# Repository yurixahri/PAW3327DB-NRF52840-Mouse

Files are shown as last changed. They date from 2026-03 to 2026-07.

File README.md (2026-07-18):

This is a mouse project for PAW3327DB‐TWQU sensor and Supermini nrf52840 board.

# Necessary components:
| component | quanlity | note |
| :--- | :---: | -----|
| Supermini nrf52840 | 2 | |
| PAW3327DB‐TWQU | 1 | please buy with its len and led |
| TTP223 touch sensor | 2 | buy the chip, not the board |
| 0805 100nf capacitor | 4 | |
| 0805 10uf capacitor | 2 | |
| 0805 33pf capacitor | 2 | |
| 0805 10kΩ resistor | 2 | |
| 0805 33Ω resistor | 1 | |
| Molex picoblade female 1.25mm 4 pins horizontal | 2 | for scroll and middle button |
| Molex picoblade female 1.25mm 3 pins horizontal | 2 | for left side buttons |
| Molex picoblade female 1.25mm 2 pins vertucal | 1 | for battery |
| Molex picoblade male cable 1.25mm 4,3,2 pins | several | just buy more than you need, in case of you want to adjust the cable length |
| 3x2x9 500mah battery | 1 | |
| Low profile keyboard switch | 2 | any brand will work |
| Mouse switch (2 pins) | 3 | So i used mouse switch and noticed that the its height is quite high and block the touch point on scroll pcb, so i instead use 3x6x2.5mm smd button (2 pins) |
| 6x6mm tactile switch | 2 | for DPI and reset button |
| 3 pins spdt slide switch | 1 | to turn on/off battery |

# Mouse schematic:
mouse

This PAW3327DB‐TWQU schematic is followed in the sensor data sheet (P.18 [here](https://gzhls.at/blob/ldb/e/9/c/9/db61cdd17b4364badf6f0cfc864d7ef28cb3.pdf)).
Two 33pf capacitors (C6 and C7) are sensitivity capacitor for TTP223, the range from 0 to 50pf, the larger value the less sensitivity of the TTP223.

A note for the battery that if you use 500mah or larger battery, please connect the BOOST pad on the Supermini nrf52840.



# PCB:
This design has 3 parts but i had to combine them in to one board to cut cost. You can safely cut it with handsaw, and use sand paper to smooth the edge.



# Mouse case
| component | quanlity | note |
| :--- | :---: | -----|
| M2 Hex Female-Female Standoff 4mm | 4 | for main pcb |
| M2 Hex Female-Female Standoff 10mm | 2 | for scroll pcb standoff |
| M2 bolt 6mm | several | |
| M2 nut | several | |

I followed PAW3327DB‐TWQU [datasheet](https://gzhls.at/blob/ldb/e/9/c/9/db61cdd17b4364badf6f0cfc864d7ef28cb3.pdf) (P.11-15).
In this repo i design one with autocad (i dont have knowledge about 3d print), it just a prototype but i used it for sevaral months now, seems fine.

# Firmware
There are 2 codes, one for the mouse and one for receiver. To build it please install Visual Code and install nRF Connect extension for the sake of simplicity, it will install SDK and compiler for you.
Then open those 2 folders in VS Code.



To build it, navigate to nRF connect tab and create build configuration.



For Supermini nrf52840, follow this setting.



After you completed the building, it will create the firmware at ../build/zephyr/zephyr.hex . Then use the python script (with the json file in the same folder) in this repo to convert the hex to uf2 with the command:
`python uf2conv.py "path/to/your/zephyr.hex" -c -f 0xADA52840`
Finally to flash the firmware to the board, connect your board to your computer, quickly connect reset pin to GND 2 times, when you see the led slowly fading it means the board is in bootloader mode. On your computer now will show the drive of the board, simply copy the uf2 firmware to the drive and it will flash the board.

# Notes
- In nRF build configuration, at the board target it does have uf2 option for this board, but for some reason it cant be flash to the board so i have to convert the hex myself
- In both of the code for the mouse and the receiver, there is esb address for rf signal, you should change it to your desire address (base_addr_0), and the address should be the same for both sides.


- In mouse code, i commented out some of the interupt code, last time i was testing the motion pin and interupt but it feel delay, so i kept the code with polling style. because of it the battery usage is around 1.5 days of intense use with some break (im not familiar with embedded stuff, so my code is kinda ugly).
- When mouse idle for more than 4 mins, it will shutdown until you press left click.
- DPI value in mouse code is hand measurement, i use a ruler to calculate the resolution value of the mouse sensor, around 102 is equilevent to 3200 DPI.
- Also in mouse code, i commented out the setting function, nRF have local storage for setting, but last time i used it somehow brick the board. So for safety concern i don't use that function.
- I was experimenting with some code, and made the board brick. I recommend you to update the board bootloader to newest nicenano bootloader ([here](https://github.com/adafruit/Adafruit_nRF52_Bootloader/releases)), use j-link (or if you don't have j-link usb, use a spare board like pico or rp2040 based board with Picoprobe firmware), connect correct pins to nrf52480 swd pads (swdclk, swdio and ground, use usb to power it) and upload via pyocd (open Nrf Connect terminal in visual code and run)
  ```
  pyocd erase -t nrf52840 --chip
  pyocd flash -t nrf52840 nice_nano_bootloader-0.11.0_s140_6.1.1.hex
  ```

# Demo (early prototype)
https://github.com/user-attachments/assets/07815808-ed37-4bc4-9238-eaf0a6d82ae9

New version (I cheaped out all Molex picoblade for this prototype):



# Thought
The cost per mouse is arround 12-15$, which is quite cheap to be fair, especially when you buy the components in bulk (1$ for 20 TTP223 sensors!). Goodluck if you want to make mouse!

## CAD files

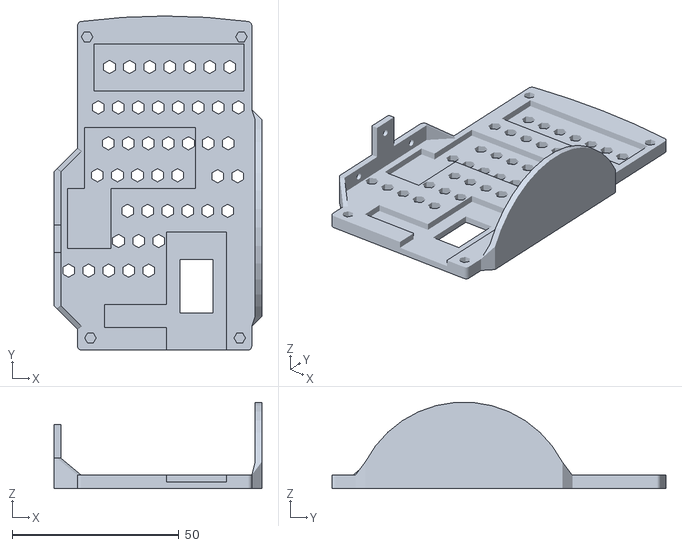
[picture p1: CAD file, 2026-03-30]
mouse3d_holes.stl
62.2 x 100.1 x 25.8

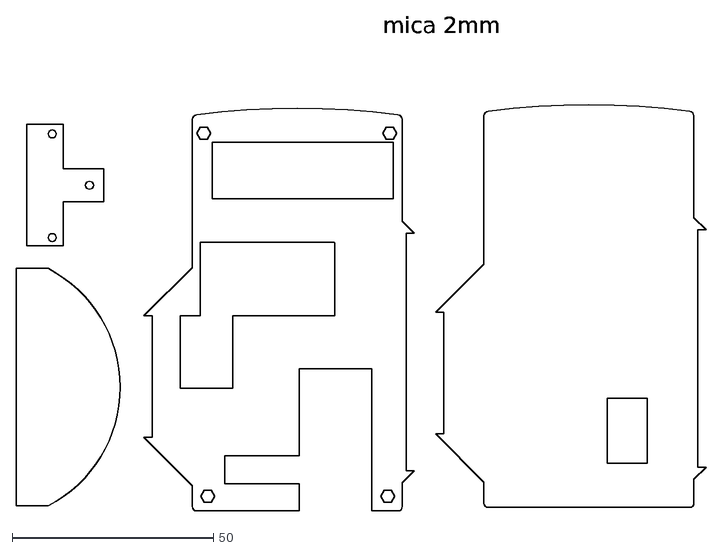
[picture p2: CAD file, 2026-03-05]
mouse.dxf
mica 2mm

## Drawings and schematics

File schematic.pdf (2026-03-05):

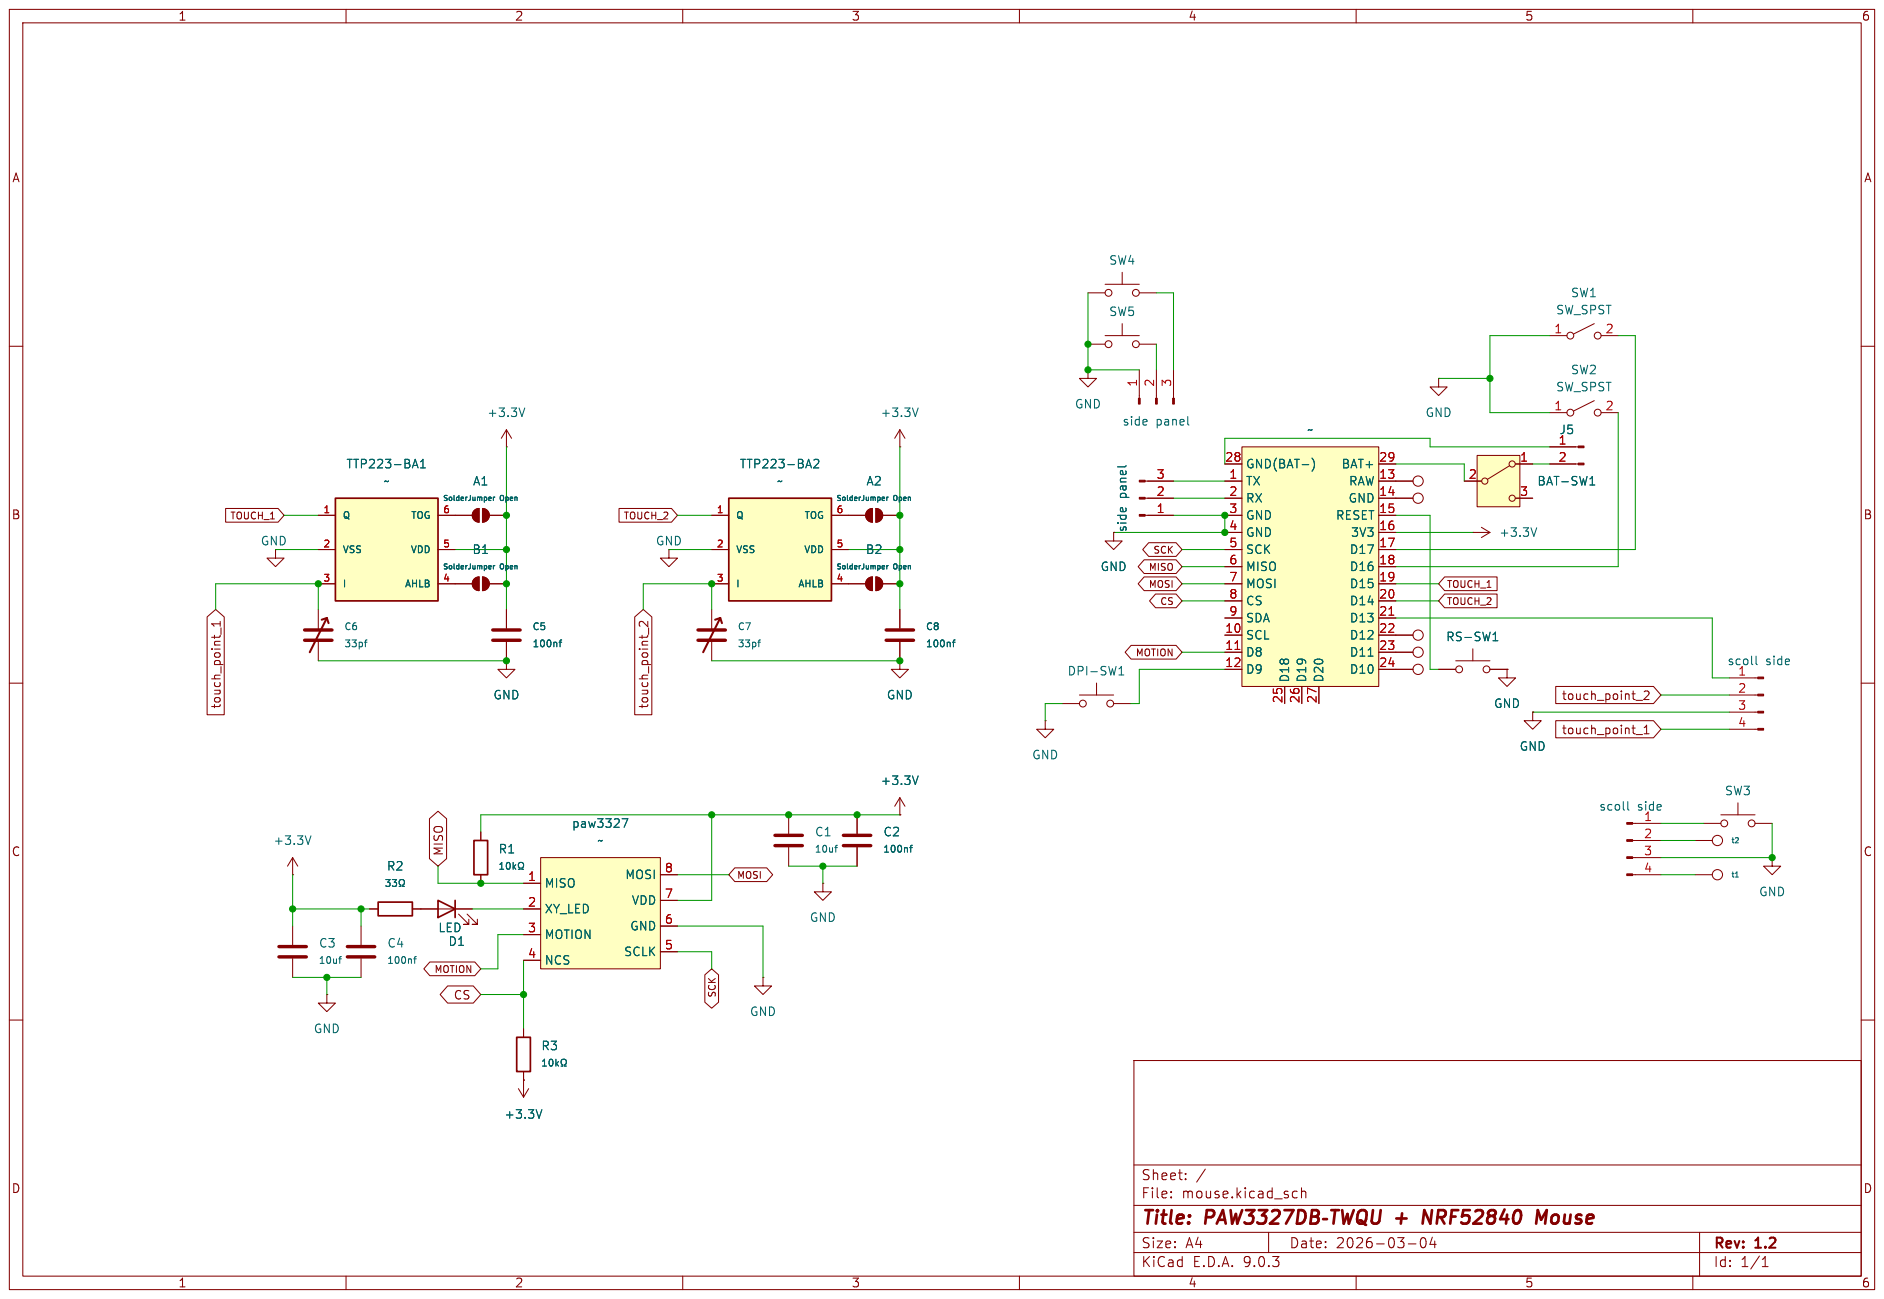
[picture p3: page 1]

SCK MISO MOSI MOTION touch_point_2

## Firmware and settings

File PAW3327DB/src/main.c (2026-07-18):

#include <stdint.h>
#include <math.h>
#include <zephyr/kernel.h>
#include <zephyr/device.h>
#include <zephyr/drivers/spi.h>
#include <zephyr/drivers/gpio.h>
#include <zephyr/logging/log.h>

#include <zephyr/usb/usb_device.h>
#include <zephyr/usb/class/usb_hid.h>
#include <zephyr/usb/usbd.h>
#include <zephyr/input/input.h>
#include <esb.h>

#include <zephyr/sys/poweroff.h>

#include <zephyr/settings/settings.h>

#include <hal/nrf_power.h>
#include <hal/nrf_clock.h>
#include <zephyr/drivers/clock_control.h>
#include <zephyr/drivers/clock_control/nrf_clock_control.h>

#include <zephyr/drivers/adc.h>
#include <hal/nrf_saadc.h>

#define M_PI       3.14159265358979323846
#define DEG_TO_RAD(degrees) ((float)(degrees) * M_PI / 180.0)

//LOG_MODULE_REGISTER(paw3327, //LOG_LEVEL_INF);
#define ADC_NODE                DT_NODELABEL(adc)    
#define ADC_RESOLUTION          12                   
#define ADC_GAIN                ADC_GAIN_1_6         
#define ADC_REFERENCE           ADC_REF_INTERNAL     
#define ADC_ACQUISITION_TIME    ADC_ACQ_TIME_DEFAULT
#define ADC_CHANNEL_ID          0                    
#define ADC_CHANNEL_INPUT       NRF_SAADC_INPUT_VDD

#define SPI_DEV                 DT_NODELABEL(spi1)
#define GPIO_0                  DT_NODELABEL(gpio0)
#define GPIO_1                  DT_NODELABEL(gpio1)
#define SCK_PIN                 17
#define MOSI_PIN                22
#define MISO_PIN                20
#define CS_PIN                  24 
#define MOTION_PIN              4  
#define BUTTON1_PIN             31  
#define BUTTON2_PIN             29 
#define BUTTON3_PIN             13
#define BUTTON4_PIN             6 
#define BUTTON5_PIN             8
#define TOUCH1_PIN              2
#define TOUCH2_PIN              15
#define DPI_PIN                 6
#define VCC_CUTOFF_GPIO_PIN     13


#define PAW3327_MOTION_REG      0x02
#define PAW3327_DELTA_X_L_REG   0x03
#define PAW3327_DELTA_X_H_REG   0x04
#define PAW3327_DELTA_Y_L_REG   0x05
#define PAW3327_DELTA_Y_H_REG   0x06
#define PAW3327_SQUAL           0x07
#define PAW3327_MOTION_BIT      0x80
#define PAW3327_BURST_REG       0x16

#define DEBOUNCE_TIME           8 //ms
#define SCROLL_DELAY_HOLD_TIME  250 //ms
#define SCROLL_INTERVAL_TIME    25 //ms

#define POLL_INTERVAL_ACTIVE_MS 1  // active polling interval
#define POLL_INTERVAL_IDLE_MS   100   // idle polling interval
#define IDLE_THRESHOLD_MS       1000*10  // time before going idle
#define SLEEP_THRESHOLD_MS      1000*60*4  // time before going to sleep
#define IDLE_SLEEP_MS           100
#define BATT_CHECK_INTERVAL     1000*60*2
#define DPI_SAVE_INTERVAL_MS         1000*5 // only save DPI to flash every 5 seconds to reduce flash wear

const uint8_t mouse_dpi[] = {11, 21, 42, 84, 126};
const uint8_t mouse_dpi_size = sizeof(mouse_dpi) / sizeof(mouse_dpi[0]);
uint8_t current_dpi = 3;

/* ESB */
struct mouse_packet {
    uint8_t buttons;
    int8_t dx;
    int8_t dy;
    int8_t wheel;
} __packed;


struct paw_burst_data {
    uint8_t motion;
    uint8_t delta_x_l;
    uint8_t delta_x_h;
    uint8_t delta_y_l;
    uint8_t delta_y_h;
    uint8_t squal;
};

/* --- SPI config --- */
static const struct spi_config spi_cfg = {
    .frequency = 4000000,
    .operation = SPI_WORD_SET(8) | SPI_TRANSFER_MSB,
    .slave = 0,
    .cs = NULL,

};

static const struct device *spi_dev;
static const struct device *gpio_0_dev;
static const struct device *gpio_1_dev;


// static struct gpio_callback motion_cb_data;
// Work queue for handling SPI reads
// static struct k_work motion_work;
// Semaphore to prevent interrupt overload
// static K_SEM_DEFINE(motion_sem, 1, 1);

// struct mouse_report {
//     uint8_t buttons;
//     int8_t x;
//     int8_t y;
//     int8_t wheel;
// };

struct key_debounce{
    bool is_pressed;
    bool on_double_click;
    int64_t pressed_time;
    uint16_t de_bounce;
    uint16_t end_time;
};

bool is_package_changed = false;
bool is_dpi_button_pressed = false;

bool button_pressed[5];
int64_t de_bounce[5];

static struct mouse_packet pkt;

bool scroll_up = false;
bool scroll_down = false;

int64_t scroll_up_holding_time = 0;
int64_t scroll_down_holding_time = 0;
int64_t scroll_up_interval_time = 0;
int64_t scroll_down_interval_time = 0;

struct key_debounce button5 = {.is_pressed = false, .on_double_click = false, .pressed_time = 0, .de_bounce = 10, .end_time = 500};

void button_check(uint8_t index, struct mouse_packet *pkt, bool is_pressed, int64_t now){
    if (is_pressed){
        if (!button_pressed[index] && now - de_bounce[index] >= DEBOUNCE_TIME){
            button_pressed[index] = true;
            pkt->buttons |= BIT(index);
            de_bounce[index] = now;
            is_package_changed = true;
        }
    }else{
        if (button_pressed[index] && now - de_bounce[index] >= DEBOUNCE_TIME){
            button_pressed[index] = false;
            pkt->buttons &= ~BIT(index);
            de_bounce[index] = now;
            is_package_changed = true;
        }
    }
}

void send_mouse_report_tx(struct mouse_packet *pkt){
    struct esb_payload payload = {
        .length = sizeof(struct mouse_packet),
        .pipe = 0,
        .noack = 1,
    };
    memcpy(payload.data, pkt, sizeof(struct mouse_packet));
    if (esb_write_payload(&payload) != 0) {
        esb_flush_tx();
        esb_write_payload(&payload);
    }
}

/* --- SPI helpers --- */
static inline void cs_select(void) {
    gpio_pin_set(gpio_0_dev, CS_PIN, 0);
    // k_busy_wait(50);
}
static inline void cs_deselect(void) {
    gpio_pin_set(gpio_0_dev, CS_PIN, 1);
    // k_busy_wait(50);
}

/* --- SPI read/write --- */
static uint8_t paw_read_reg(uint8_t reg, uint8_t *data)
{
    uint8_t tx[2] = { reg & 0x7F, 0x00 };
    uint8_t rx[2] = { 0 };

    struct spi_buf txb = { .buf = tx, .len = 2 };
    struct spi_buf rxb = { .buf = rx, .len = 2 };
    struct spi_buf_set txs = { .buffers = &txb, .count = 1 };
    struct spi_buf_set rxs = { .buffers = &rxb, .count = 1 };

    cs_select();
    int ret = spi_transceive(spi_dev, &spi_cfg, &txs, &rxs);
    cs_deselect();
    if (ret) {
        //LOG_ERR("SPI read error %d", ret);
        return ret;
    }
    *data = rx[1];
    return 0;
}

static void paw_write_reg(uint8_t reg, uint8_t val)
{
    uint8_t tx[2] = { reg | 0x80, val };
    struct spi_buf b = { .buf = tx, .len = 2 };
    struct spi_buf_set txs = { .buffers = &b, .count = 1 };

    cs_select();
    spi_write(spi_dev, &spi_cfg, &txs);
    cs_deselect();
}

/* --- Burst motion read (0x16) --- */
static int paw_read_burst(struct paw_burst_data *burst_data) {
    uint8_t cmd = 0x16;

    struct spi_buf txb = { .buf = &cmd, .len = 1 };
    struct spi_buf_set tx = { .buffers = &txb, .count = 1 };

    cs_select();
    spi_write(spi_dev, &spi_cfg, &tx);

    k_usleep(35);

    uint8_t tx_dummy[7] = {0};
    uint8_t rx_buf[7] = {0};

    struct spi_buf txb2 = { .buf = tx_dummy, .len = 7 };
    struct spi_buf rxb2 = { .buf = rx_buf, .len = 7 };

    struct spi_buf_set tx2 = { .buffers = &txb2, .count = 1 };
    struct spi_buf_set rx2 = { .buffers = &rxb2, .count = 1 };

    spi_transceive(spi_dev, &spi_cfg, &tx2, &rx2);
    cs_deselect();

    burst_data->motion     = rx_buf[1];
    burst_data->delta_x_l  = rx_buf[2];
    burst_data->delta_x_h  = rx_buf[3];
    burst_data->delta_y_l  = rx_buf[4];
    burst_data->delta_y_h  = rx_buf[5];
    burst_data->squal      = rx_buf[6];
    k_usleep(250);
    
    return 0;
}

void paw3327_init(void){
    uint8_t id, inv, dummy;

    //LOG_INF("Initializing PAW3327...");

    /* Power-up reset */
    paw_write_reg(0x3A, 0x5A);      // POWER_UP_RESET
    k_msleep(50);

    /* Verify product ID */
    paw_read_reg(0x00, &id);        // PRODUCT_ID
    paw_read_reg(0x3F, &inv);       // INV_PRODUCT_ID
    //LOG_INF("Product ID=0x%02X, Inverse ID=0x%02X", id, inv);
    if (id != 0x4C || inv != 0xB3) {
        //LOG_WRN("Unexpected ID values! Check SPI polarity/mode.");
    }

    /* Exit shutdown */
    paw_write_reg(0x3B, 0x00);      // SHUTDOWN = 0 → Active mode
    k_msleep(50);              // Allow internal oscillator & LED to stabilize

    /* Optional internal setup (safe defaults) */
    paw_write_reg(0x1A, 0x03);      // RIPPLE_CONTROL (default)
    paw_write_reg(0x1B, mouse_dpi[current_dpi]);     // CPI_SETTING
    paw_write_reg(0x1E, 0x00);      // ANGLE_SNAP default
    paw_write_reg(0x20, 0x00);      // AXIS_CONTROL normal

    /* Dummy read to clear motion latch */
    paw_read_reg(0x01, &dummy);
    paw_read_reg(0x02, &dummy);
    paw_read_reg(0x03, &dummy);
    paw_read_reg(0x04, &dummy);
    paw_read_reg(0x05, &dummy);

    k_msleep(10);
    //LOG_INF("Resolution %d", dummy);
    //LOG_INF("PAW3327 initialization complete");
}

// void ensure_hfclk_running(void) {
//     // Check if high-frequency clock (HFXO) is running
//     if (!nrf_clock_hf_is_running(NRF_CLOCK, NRF_CLOCK_HFCLK_HIGH_ACCURACY)) {

//         // Start the external high-frequency crystal oscillator
//         nrf_clock_task_trigger(NRF_CLOCK, NRF_CLOCK_TASK_HFCLKSTART);

//         /* Wait until the HFCLK is ready */
//         while (!nrf_clock_hf_is_running(NRF_CLOCK, NRF_CLOCK_HFCLK_HIGH_ACCURACY)) {
//             k_busy_wait(10);
//         }
//     }
// }

void start_hfxo_properly(void) {
    const struct device *clk_dev = DEVICE_DT_GET(DT_NODELABEL(clock));
    
    // Request the HFXO (High Frequency Crystal Oscillator)
    // This is "clock-aware" and more efficient than a manual busy-wait
    clock_control_on(clk_dev, CLOCK_CONTROL_NRF_SUBSYS_HF);
}

// static int dpi_settings_set(const char *name, size_t len, settings_read_cb read_cb, void *cb_arg){
//     const char *next;
//     int rc;

//     if (settings_name_steq(name, "index", &next) && !next) {
//         if (len != sizeof(current_dpi)) {
//             return -EINVAL;
//         }
//         rc = read_cb(cb_arg, &current_dpi, sizeof(current_dpi));
//         if (rc >= 0) {
//             return 0;
//         }
//         return rc;
//     }
//     return -ENOENT;
// }

// struct settings_handler dpi_settings_handler = {
//     .name = "dpi",
//     .h_set = dpi_settings_set,
// };

// static struct k_work dpi_save_work;

// static void dpi_save_work_handler(struct k_work *work)
// {
//     ARG_UNUSED(work);
//     //LOG_ERR(">> dpi_save_work_handler: saving dpi=%u\n", current_dpi);
//     int rc = settings_save_one("dpi/index", &current_dpi, sizeof(current_dpi));
//     //LOG_ERR(">> settings_save_one returned %d\n", rc);
//     if (rc) {
//         //LOG_ERR("Failed to save dpi: %d", rc);
//     } else {
//         //LOG_INF("Saved dpi index=%u", current_dpi);
//     }
// }
static int dpi_setting_set(const char *name, size_t len, settings_read_cb read_cb, void *cb_arg) {
    if (strcmp(name, "dpi") == 0) {
        read_cb(cb_arg, &current_dpi, sizeof(current_dpi));
        return 0;
    }
    return -ENOENT;
}

static struct settings_handler dpi_handler = {
    .name = "mouse",
    .h_set = dpi_setting_set
};

void save_dpi() {
    //LOG_INF("DPI saved to %d\n", current_dpi);
    settings_save_one("mouse/dpi", &current_dpi, sizeof(current_dpi));
}

void change_dpi(){
    current_dpi++;
    if (current_dpi >= mouse_dpi_size){
        current_dpi = 0;
    }
    //LOG_INF("DPI changed to %d\n", current_dpi);
    paw_write_reg(0x1B, mouse_dpi[current_dpi]);
}

void event_handler(struct esb_evt const *event){
    switch (event->evt_id) {
        case ESB_EVENT_TX_SUCCESS:
            break;
        case ESB_EVENT_TX_FAILED:
            esb_flush_tx();
            break;
        default:
            break;
    }
}

int esb_init_tx(void){
    /* These are arbitrary default addresses. In end user products
	 * different addresses should be used for each set of devices.
	 */
    uint8_t base_addr_0[4] = {0xE7, 0xE7, 0xE7, 0xE7};
	uint8_t base_addr_1[4] = {0xC2, 0xC2, 0xC2, 0xC2};
	uint8_t addr_prefix[8] = {0xE7, 0xC2, 0xC3, 0xC4, 0xC5, 0xC6, 0xC7, 0xC8};

    struct esb_config config = ESB_DEFAULT_CONFIG;
    config.mode = ESB_MODE_PTX; // Receiver mode
    config.event_handler = event_handler;
    config.bitrate = ESB_BITRATE_2MBPS;
    config.protocol = ESB_PROTOCOL_ESB_DPL;
    config.selective_auto_ack = true;
    config.tx_output_power = ESB_TX_POWER_4DBM;
    config.retransmit_count = 3;
    config.retransmit_delay = 250; // in microseconds
    

    if (IS_ENABLED(CONFIG_ESB_FAST_SWITCHING)) {
		config.use_fast_ramp_up = true;
	}

    int err = esb_init(&config);
    err = esb_set_base_address_0(base_addr_0);
    if (err) {
        return err;
    }
    err = esb_set_prefixes(addr_prefix, ARRAY_SIZE(addr_prefix));
    if (err) {
        return err;
    }
        
    return 0;
}
    
    /* --- Main --- */
int main(void){

    k_msleep(200); // Wait for system to stabilize

    int err;
    settings_subsys_init();
    settings_register(&dpi_handler);
    settings_load();
    //LOG_INF("Loaded DPI from flash: %d\n", current_dpi);
    // if (err) {
    //     //LOG_ERR("Error reading DPI from flash: %d\n", err);
    //     while(1) { k_msleep(1000); }
    // }


    nrf_power_dcdcen_set(NRF_POWER, true);
    start_hfxo_properly();
    // ensure_hfclk_running();
    err = esb_init_tx();
	if (err) {
		//LOG_ERR("ESB initialization failed, err %d", err);
		return 0;
	}

    // k_msleep(3000);

    //LOG_INF("PAW3327 start test...\n");
    spi_dev = DEVICE_DT_GET(SPI_DEV);
    gpio_0_dev = DEVICE_DT_GET(GPIO_0);
    gpio_1_dev = DEVICE_DT_GET(GPIO_1);

    if (!device_is_ready(spi_dev)) {
        //LOG_ERR("SPI not ready\n");
        return -ENODEV;
    }

    if (!device_is_ready(gpio_0_dev) || !device_is_ready(gpio_1_dev)) {
        //LOG_ERR("Devices not ready");
        return 1;
    }

    gpio_pin_configure(gpio_0_dev, CS_PIN, GPIO_OUTPUT_HIGH);
    gpio_pin_configure(gpio_1_dev, MOTION_PIN, GPIO_INPUT | GPIO_PULL_UP);

    gpio_pin_configure(gpio_0_dev, BUTTON1_PIN, GPIO_INPUT | GPIO_PULL_UP);
    gpio_pin_configure(gpio_0_dev, BUTTON2_PIN, GPIO_INPUT | GPIO_PULL_UP);
    gpio_pin_configure(gpio_1_dev, BUTTON3_PIN, GPIO_INPUT | GPIO_PULL_UP);
    gpio_pin_configure(gpio_0_dev, BUTTON4_PIN, GPIO_INPUT | GPIO_PULL_UP);
    gpio_pin_configure(gpio_0_dev, BUTTON5_PIN, GPIO_INPUT | GPIO_PULL_UP);
    gpio_pin_configure(gpio_0_dev, TOUCH1_PIN, GPIO_INPUT );
    gpio_pin_configure(gpio_1_dev, TOUCH2_PIN, GPIO_INPUT );
    gpio_pin_configure(gpio_1_dev, DPI_PIN, GPIO_INPUT | GPIO_PULL_UP);

    gpio_pin_configure(gpio_0_dev, VCC_CUTOFF_GPIO_PIN, GPIO_OUTPUT_ACTIVE);
    gpio_pin_set(gpio_0_dev, VCC_CUTOFF_GPIO_PIN, 1);

    // Initialize the work queue item
    // k_work_init(&motion_work, motion_handler);
    // err = gpio_pin_interrupt_configure(gpio_1_dev, MOTION_PIN, GPIO_INT_EDGE_FALLING);
    // if (err) {
    //     //LOG_ERR("Error configuring motion interrupt: %d", err);
    //     return err;
    // }
    // gpio_init_callback(&motion_cb_data, motion_callback, BIT(MOTION_PIN));
    // gpio_add_callback(gpio_1_dev, &motion_cb_data);
    
    paw3327_init();
    
    int64_t sleep_time = 0;
    int64_t last_dpi_save = 0;
    bool is_dpi_save_pending = false;
    int current_poll_interval = POLL_INTERVAL_ACTIVE_MS;

    struct k_timer polling_timer;
    k_timer_init(&polling_timer, NULL, NULL);
    k_timer_start(&polling_timer, K_MSEC(current_poll_interval), K_MSEC(current_poll_interval));
    // bool is_sensor_sleeping = false;
    // float scale = 1.49f;
    while (1) {
        int64_t now = k_uptime_get();
        k_timer_status_sync(&polling_timer);
        // bool wake_event = !gpio_pin_get(gpio_0_dev, BUTTON1_PIN) ||
        //               !gpio_pin_get(gpio_0_dev, BUTTON2_PIN);

        // if (is_sensor_sleeping && wake_event) {
        //     gpio_pin_set(gpio_0_dev, VCC_CUTOFF_GPIO_PIN, 1);
        //     esb_init_tx();
        //     k_msleep(50);
        //     paw_write_reg(0x1B, 0xC0);
        //     paw_write_reg(0x1A, 0x03);
        //     is_sensor_sleeping = false;
        //     sleep_time = now;
        // }

        struct paw_burst_data burst;
        pkt.dx = 0;
        pkt.dy = 0;
        int motion_pin_state = gpio_pin_get(gpio_1_dev, MOTION_PIN);
        if (motion_pin_state == 0) {
            if (paw_read_burst(&burst) == 0 ) { //
                if (burst.motion & PAW3327_MOTION_BIT && burst.squal > 10 ) { //
                    
                    int16_t dx = ((burst.delta_x_h << 8) | burst.delta_x_l);
                    int16_t dy = ((burst.delta_y_h << 8) | burst.delta_y_l);
                    
                    dx = CLAMP(dx, -127, 127) ;
                    dy = CLAMP(dy, -127, 127) ;
                    // // flip x
                    dx *= -1;

                    pkt.dx =  dx;
                    pkt.dy =  dy;
                    is_package_changed = true;
                }
            }
        }

        button_check(0, &pkt, !gpio_pin_get(gpio_0_dev, BUTTON1_PIN), now);
        button_check(1, &pkt, !gpio_pin_get(gpio_0_dev, BUTTON2_PIN), now);
        button_check(2, &pkt, !gpio_pin_get(gpio_1_dev, BUTTON3_PIN), now);
        button_check(4, &pkt, !gpio_pin_get(gpio_0_dev, BUTTON4_PIN), now);
        button_check(3, &pkt, !gpio_pin_get(gpio_0_dev, BUTTON5_PIN), now);

        // DPI button
        if (!gpio_pin_get(gpio_1_dev, DPI_PIN)){
            if (!is_dpi_button_pressed){
                change_dpi();
                last_dpi_save = now;
                is_dpi_save_pending = true;
                is_dpi_button_pressed = true;
            }
        }else{
            if (is_dpi_button_pressed)
                is_dpi_button_pressed = false;
        }

        if(gpio_pin_get(gpio_0_dev, TOUCH1_PIN)){
            //if (!scroll_up) scroll_up_holding_time = now;
            if (!scroll_up || (now - scroll_up_holding_time >= SCROLL_DELAY_HOLD_TIME && now - scroll_up_interval_time >= SCROLL_INTERVAL_TIME)){
                pkt.wheel = 1;
                is_package_changed = true;
                scroll_up = true;
                scroll_up_interval_time = now;
            }
        }else{
            scroll_up_holding_time = now;
            scroll_up = false;
        }
        if (gpio_pin_get(gpio_1_dev, TOUCH2_PIN)){
            //if (!scroll_down) scroll_down_holding_time = now;
            if (!scroll_down || (now - scroll_down_holding_time >= SCROLL_DELAY_HOLD_TIME && now - scroll_down_interval_time >= SCROLL_INTERVAL_TIME)){
                pkt.wheel = -1;
                is_package_changed = true;
                scroll_down = true;
                scroll_down_interval_time = now;
            }
        }else{
            scroll_down_holding_time = now;
            scroll_down = false;
        }

        if (gpio_pin_get(gpio_0_dev, TOUCH1_PIN) && gpio_pin_get(gpio_1_dev, TOUCH2_PIN)) {
            pkt.wheel = 0;
            is_package_changed = true;
        }else if(!gpio_pin_get(gpio_0_dev, TOUCH1_PIN) && !gpio_pin_get(gpio_1_dev, TOUCH2_PIN)){
            if  (pkt.wheel != 0){
                pkt.wheel = 0;
                is_package_changed = true;
            }           
        }

        if (is_package_changed){
            //LOG_INF("Sending packet: buttons=%02X, dx=%d, dy=%d, wheel=%d\n", pkt.buttons, pkt.dx, pkt.dy, pkt.wheel);
            send_mouse_report_tx(&pkt);
            is_package_changed = false;
            pkt.wheel = 0;
            sleep_time = now;
            if (current_poll_interval != POLL_INTERVAL_ACTIVE_MS){
                current_poll_interval = POLL_INTERVAL_ACTIVE_MS;
                esb_init_tx();
                k_timer_start(&polling_timer, K_MSEC(current_poll_interval), K_MSEC(current_poll_interval));
            }
        }

        if (now - sleep_time >= SLEEP_THRESHOLD_MS) {
            // if (!is_sensor_sleeping) {
                //     is_sensor_sleeping = true;
                //     esb_disable();
                // }
            gpio_pin_set(gpio_0_dev, VCC_CUTOFF_GPIO_PIN, 0);

            gpio_pin_configure(gpio_0_dev, CS_PIN, GPIO_DISCONNECTED);
            gpio_pin_configure(gpio_0_dev, SCK_PIN, GPIO_DISCONNECTED);
            gpio_pin_configure(gpio_0_dev, MOSI_PIN, GPIO_DISCONNECTED);
            gpio_pin_configure(gpio_0_dev, MISO_PIN, GPIO_DISCONNECTED);

            gpio_pin_configure(gpio_0_dev, TOUCH1_PIN, GPIO_DISCONNECTED);
            gpio_pin_configure(gpio_1_dev, TOUCH2_PIN, GPIO_DISCONNECTED);

            gpio_pin_interrupt_configure(gpio_0_dev, BUTTON1_PIN, GPIO_INT_LEVEL_LOW | GPIO_INT_WAKEUP);
            //gpio_pin_interrupt_configure(gpio_0_dev, BUTTON2_PIN, GPIO_INT_LEVEL_LOW | GPIO_INT_WAKEUP);

            k_msleep(200);
            sys_poweroff();
            //k_msleep(IDLE_SLEEP_MS);
        }else if (now - sleep_time >= IDLE_THRESHOLD_MS && current_poll_interval != POLL_INTERVAL_IDLE_MS) {
            current_poll_interval = POLL_INTERVAL_IDLE_MS;
            esb_disable();
            k_timer_start(&polling_timer, K_MSEC(current_poll_interval), K_MSEC(current_poll_interval));
        }

        if(!is_dpi_button_pressed && is_dpi_save_pending && now - last_dpi_save >= DPI_SAVE_INTERVAL_MS){
            save_dpi();
            is_dpi_save_pending = false;
        }
        // if (current_poll_interval != POLL_INTERVAL_CPU_CLOCK) {
        //     k_msleep(current_poll_interval);
        //     /* debug print ESB state while idle */
        //     //LOG_ERR("ESB state: OFF\n");
        // }else{
        //     while (k_cycle_get_32() - deadline < 0) {
                
        //     }
        // }
    }

    return 0;
}

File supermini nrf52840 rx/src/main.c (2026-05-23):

#include <stdint.h>
#include <zephyr/kernel.h>
#include <zephyr/usb/usb_device.h>
#include <zephyr/usb/class/usb_hid.h>
#include <zephyr/usb/usbd.h>
#include <zephyr/input/input.h>
#include <zephyr/logging/log.h>
#include <esb.h>

LOG_MODULE_REGISTER(mouse_rx, LOG_LEVEL_INF);

const struct device *hid_dev;
static enum usb_dc_status_code usb_status;
static K_SEM_DEFINE(ep_write_sem, 0, 1);
static inline void status_cb(enum usb_dc_status_code status, const uint8_t *param){
	usb_status = status;
    switch (status){
        case USB_DC_CONFIGURED:
            k_sem_give(&ep_write_sem);
            break;
        default:
            break;
    }
}
static void int_in_ready_cb(const struct device *dev){
	ARG_UNUSED(dev);
	k_sem_give(&ep_write_sem);
}
static const uint8_t hid_report_desc[] = HID_MOUSE_REPORT_DESC(5);
static const struct hid_ops ops = {
	.int_in_ready = int_in_ready_cb,
};

// struct mouse_report {
//     uint8_t buttons;
//     int8_t x;
//     int8_t y;
//     int8_t wheel;
// };

struct mouse_packet {
    uint8_t buttons;
    int8_t dx;
    int8_t dy;
    int8_t wheel;
} __packed;

K_MSGQ_DEFINE(mouse_report_queue, sizeof(struct mouse_packet), 1000, 4);

/* HID*/
void send_mouse_report(struct mouse_packet *report){
    // static struct mouse_report report = { 0, 0, 0, 0 };

    // report.buttons = packet->buttons;   // Button bitmask (0 = none pressed)
    // report.x = packet->dx;     // ΔX
    // report.y = packet->dy;     // ΔY
    // report.wheel = packet->wheel;
    // LOG_INF("HID report: BTN=0x%02X, DX=%d, DY=%d, WH=%d",
    //         report[0], (int8_t)report[1], (int8_t)report[2], (int8_t)report[3]);

    k_sem_take(&ep_write_sem, K_MSEC(1)); // Wait for previous transfer to complete
    hid_int_ep_write(hid_dev, (const uint8_t *)report, sizeof(*report), NULL);
    // if (report->wheel != 0) {
    //     report->wheel = 0;
    //     report->dx = 0;
    //     report->dy = 0;
    //     k_sem_take(&ep_write_sem, K_MSEC(1)); 
    //     hid_int_ep_write(hid_dev, (const uint8_t *)report, sizeof(*report), NULL);
    // }
}



void event_handler(struct esb_evt const *event){
    if (event->evt_id == ESB_EVENT_RX_RECEIVED) {
        struct esb_payload payload;
        while (esb_read_rx_payload(&payload) == 0) {
            struct mouse_packet *pkt = (struct mouse_packet *)payload.data;
            k_msgq_put(&mouse_report_queue, pkt, K_NO_WAIT);
            // send_mouse_report(pkt);
            // LOG_INF("dx=%d dy=%d btn=%02X", pkt->dx, pkt->dy, pkt->buttons);

            // TODO: send via HID here
            // send_mouse_report(hid_dev, pkt->dx, pkt->dy, pkt->wheel, 
            //                   pkt->buttons & 1, pkt->buttons & 2, pkt->buttons & 4, pkt->buttons & 8, pkt->buttons & 16);
        }
    }
}

void hid_send_thread(void *p1, void *p2, void *p3) {
    struct mouse_packet report;

    while (true) {
        // Block until a new report is available in the queue
        k_msgq_get(&mouse_report_queue, &report, K_FOREVER);

        // Now, send the HID report safely from the thread context
        if (hid_dev != NULL) {
            send_mouse_report(&report);
        }
    }
}
K_THREAD_DEFINE(hid_send_thread_id, 1024*4, hid_send_thread, NULL, NULL, NULL, 5, 0, 0);

int esb_init_rx(void) {
    /* These are arbitrary default addresses. In end user products
	 * different addresses should be used for each set of devices.
	 */
    uint8_t base_addr_0[4] = {0xE7, 0xE7, 0xE7, 0xE7};
	uint8_t base_addr_1[4] = {0xC2, 0xC2, 0xC2, 0xC2};
	uint8_t addr_prefix[8] = {0xE7, 0xC2, 0xC3, 0xC4, 0xC5, 0xC6, 0xC7, 0xC8};

    struct esb_config config = ESB_DEFAULT_CONFIG;
    config.mode = ESB_MODE_PRX; // Receiver mode
    config.event_handler = event_handler;
    config.bitrate = ESB_BITRATE_2MBPS;
    config.protocol = ESB_PROTOCOL_ESB_DPL;
    config.selective_auto_ack = true;
    config.tx_output_power = ESB_TX_POWER_4DBM;

    if (IS_ENABLED(CONFIG_ESB_FAST_SWITCHING)) {
		config.use_fast_ramp_up = true;
	}

    int err = esb_init(&config);
    err = esb_set_base_address_0(base_addr_0);
    if (err) {
            return err;
    }
    err = esb_set_prefixes(addr_prefix, ARRAY_SIZE(addr_prefix));
	if (err) {
		return err;
	}
    
    return 0;
}

void hid_init(){
    hid_dev = device_get_binding("HID_0");
    if (!hid_dev) {
        LOG_ERR("Cannot find HID device");
        return;
    }

    usb_hid_register_device(hid_dev,
				hid_report_desc, sizeof(hid_report_desc),
				&ops);

	usb_hid_init(hid_dev);

    // int ret = usb_enable(status_cb);
    // if (ret != 0) {
    //     LOG_ERR("Failed to enable USB: %d", ret);
    //     return;
    // }

    LOG_INF("USB HID ready");
}

int main(void){
    hid_init();
    int err;
    err = esb_init_rx();
	if (err) {
		LOG_ERR("ESB initialization failed, err %d", err);
		return 0;
	}

    err = esb_start_rx();
	if (err) {
		LOG_ERR("RX setup failed, err %d", err);
		return 0;
	}

    LOG_INF("Initialization complete");

    while (1) {
        k_sleep(K_MSEC(50));
    }
    return 0;
}

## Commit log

2026-03-05 case for mouse
    [mouse.dxf]
2026-03-23 for 3d print
    autocad does have 3d modelling
    [mouse3d.stl]
2026-03-27 add middle button
2026-03-27 Revise mouse switch note in README
    Updated mouse switch note for clarity regarding height issues and alternative component used.
2026-03-30 fixed left width, smaller 5mm
    [mouse3d_holes.stl]
2026-05-23 increase rf range, so it can work up to 15 meters, also help receiver communicate through the custom 3d case.
2026-07-18 - add settings to store dpi for next session - improve battery life with careful loop, idle timeout
2026-07-18 Update README with bootloader recovery instructions
    Added instructions for updating the board bootloader and recovering from a bricked state.
